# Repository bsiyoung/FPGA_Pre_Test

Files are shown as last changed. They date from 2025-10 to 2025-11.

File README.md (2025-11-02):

# FPGA_Pre_Test

This simple project is for testing power rails and external oscillator to use them on FPGA circuit design.

## 1. Objectives
1. Check power rails ON/OFF sequencing works properly
2. Check oscillator(25MHz) works properly
3. Get output voltage ripple data by
    + different output capacitance(~200uF) of buck converter
    + different output voltages(1.0~5.0V) of buck converter
    + different load(resistive, ~1.5W consume)

## 2. Directores
|Directory|Description|
|---|---|
|calculation|files for calculation|
|datasheet|datasheets of components|
|diagrams|diagrams images|
|eda_model|EDA model files for KiCAD|
|kicad_proj|KiCAD project directory|
|pcb|PCB images and gerber file|
|readme_img|image for readme file|
|schematic|schematic jpg and pdf file|

## 3. Architecture Diagram
### 3.1 Module Diagram
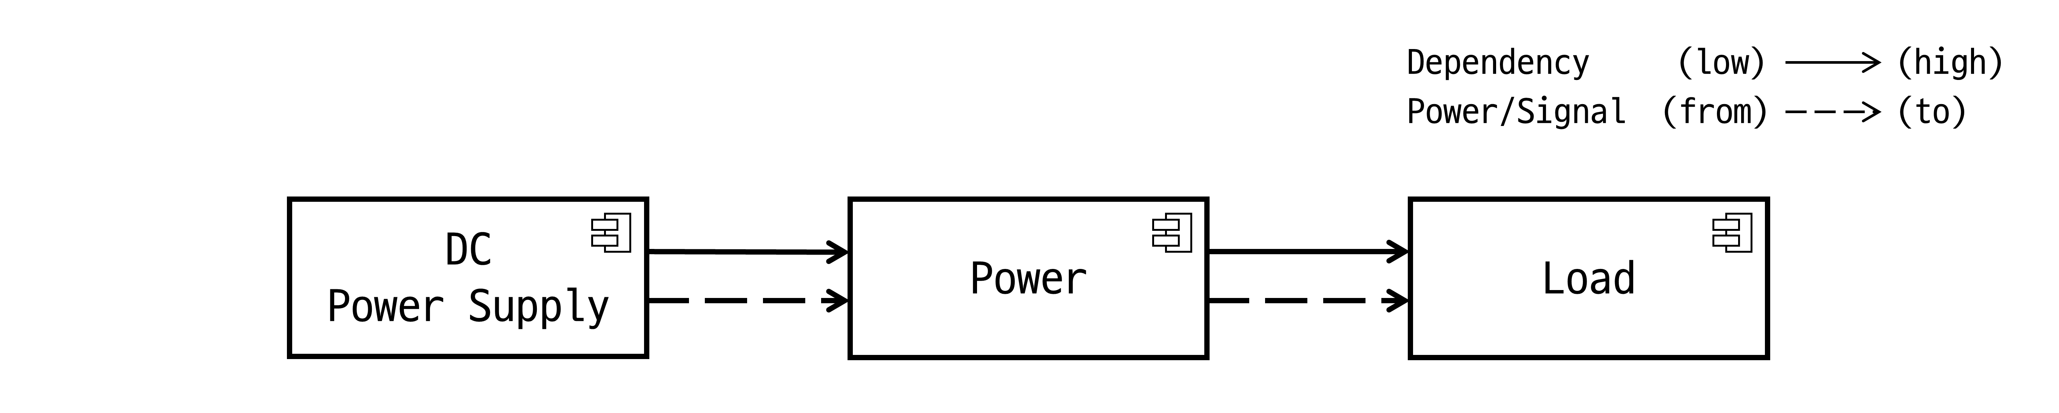
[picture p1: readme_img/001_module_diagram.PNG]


### 3.2 Block Diagram
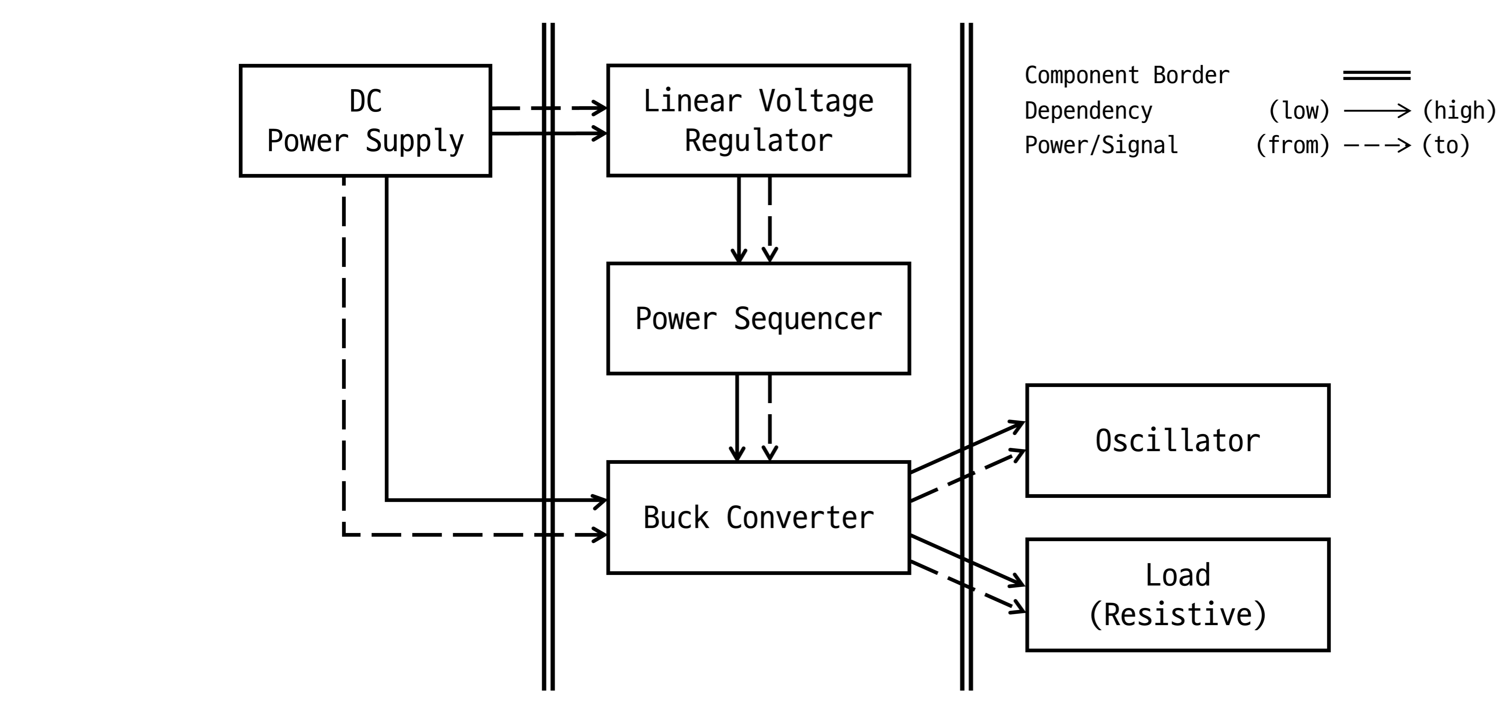
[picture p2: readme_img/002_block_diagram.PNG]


### 3.3 Ports Diagram
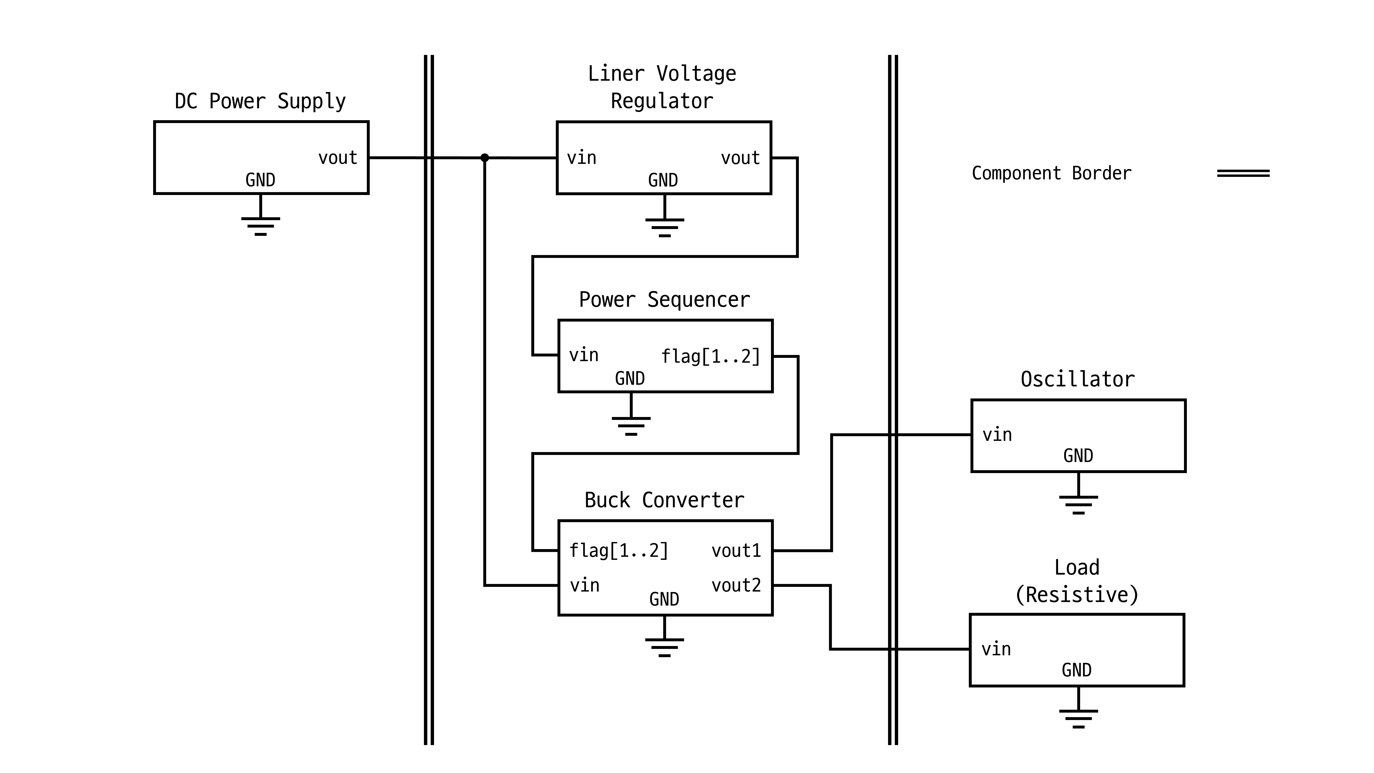
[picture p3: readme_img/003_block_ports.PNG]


## 4. Circuit Schematic
Footprints of resistors R16~20 will be used as solder jumper.

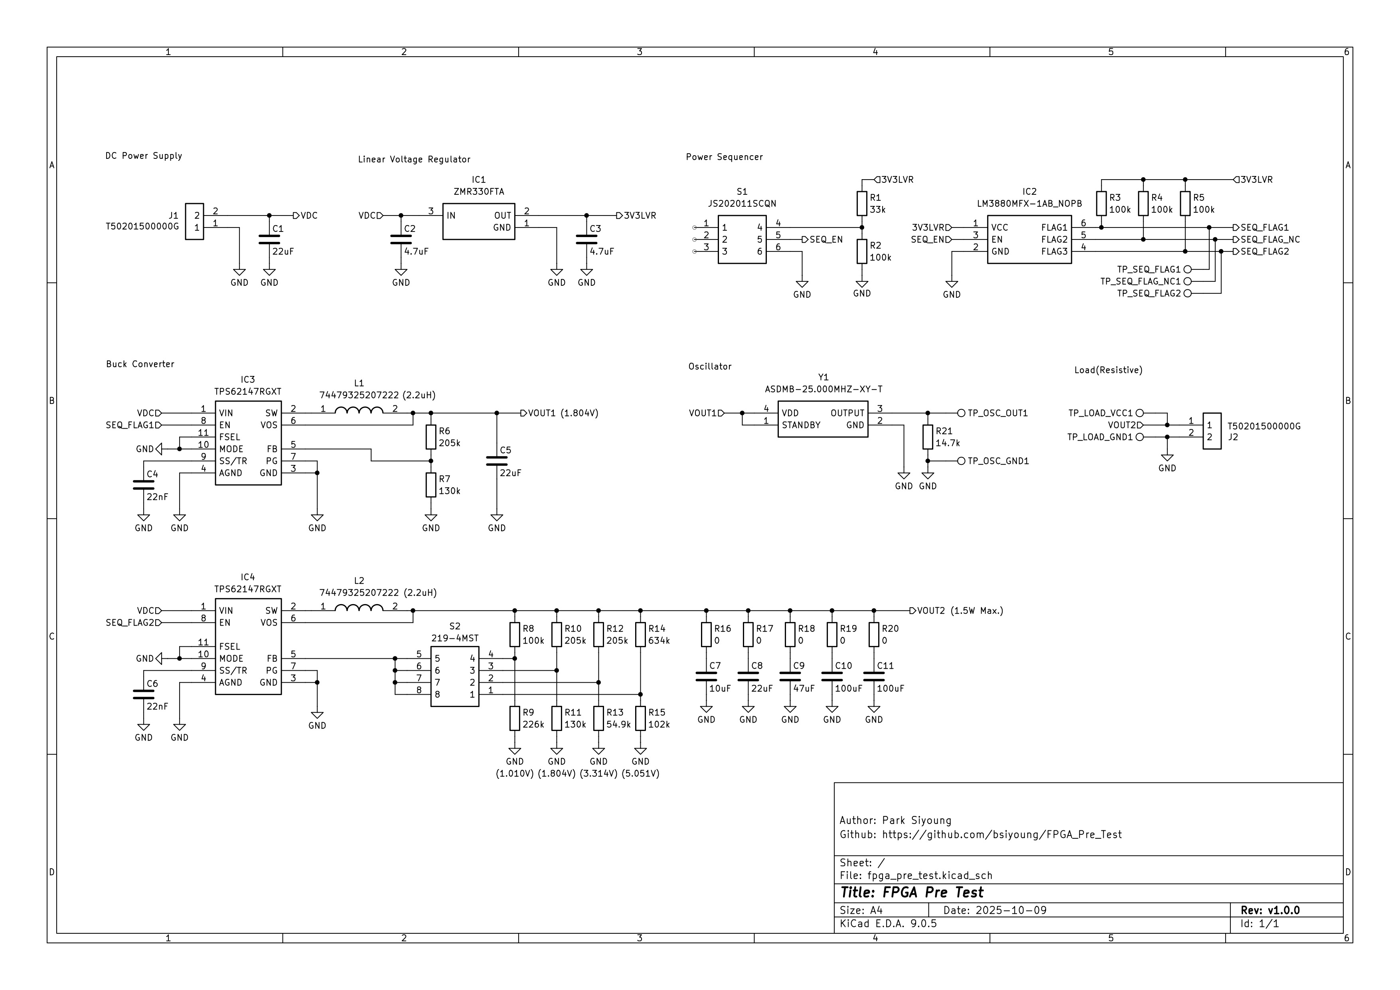
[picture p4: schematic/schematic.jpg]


</br>
Date of basis for price calculation : 2025.10.21. </br>
Refer to <a href="./component_list.xlsx">component_list.xlsx</a> for details. </br>
* Exclude PCB(USD$20.84/5pcs) and resistive load(USD$8.40).

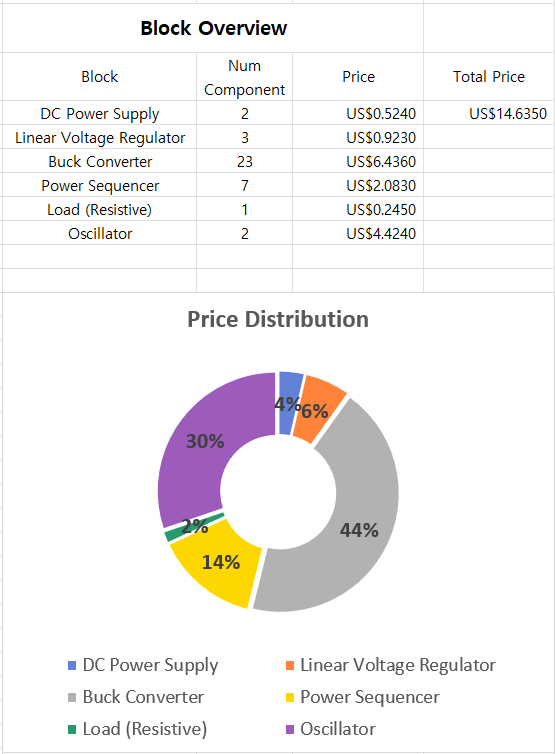
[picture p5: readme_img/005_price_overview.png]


</br>
<b>Total: USD$27.203/pcs</b> (incldue PCB and resistive load)

## 5. PCB Design
Manufacturer : JLC PCB </br>
Gerber File : ./pcb/pcb_gerber.zip (zip file of ./kicad_proj/output)

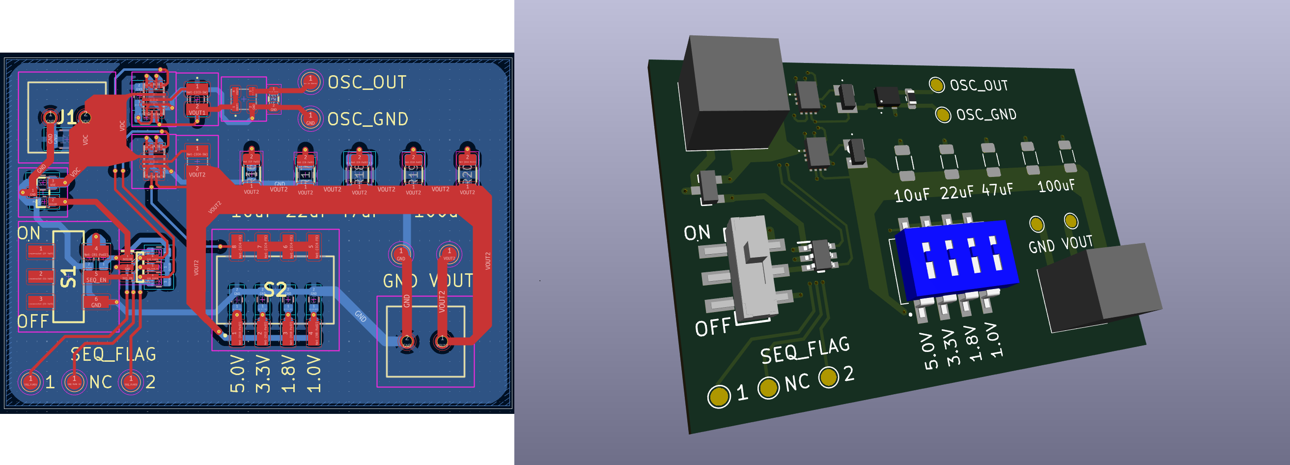
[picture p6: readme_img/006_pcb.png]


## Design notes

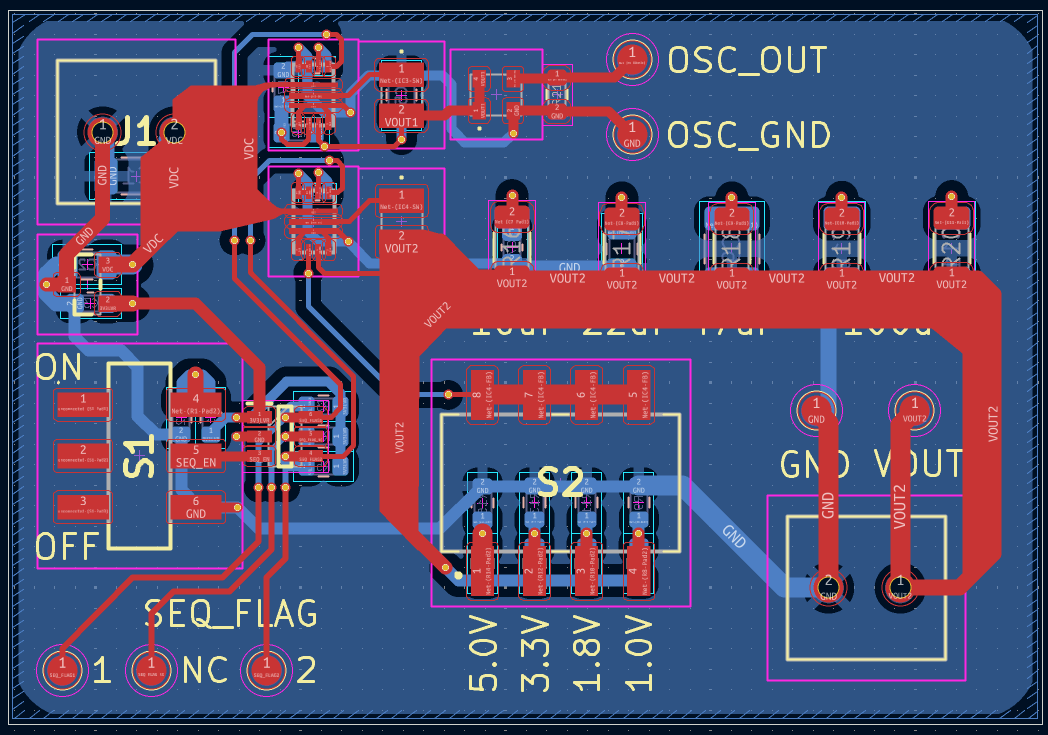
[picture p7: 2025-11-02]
pcb/pcb.png

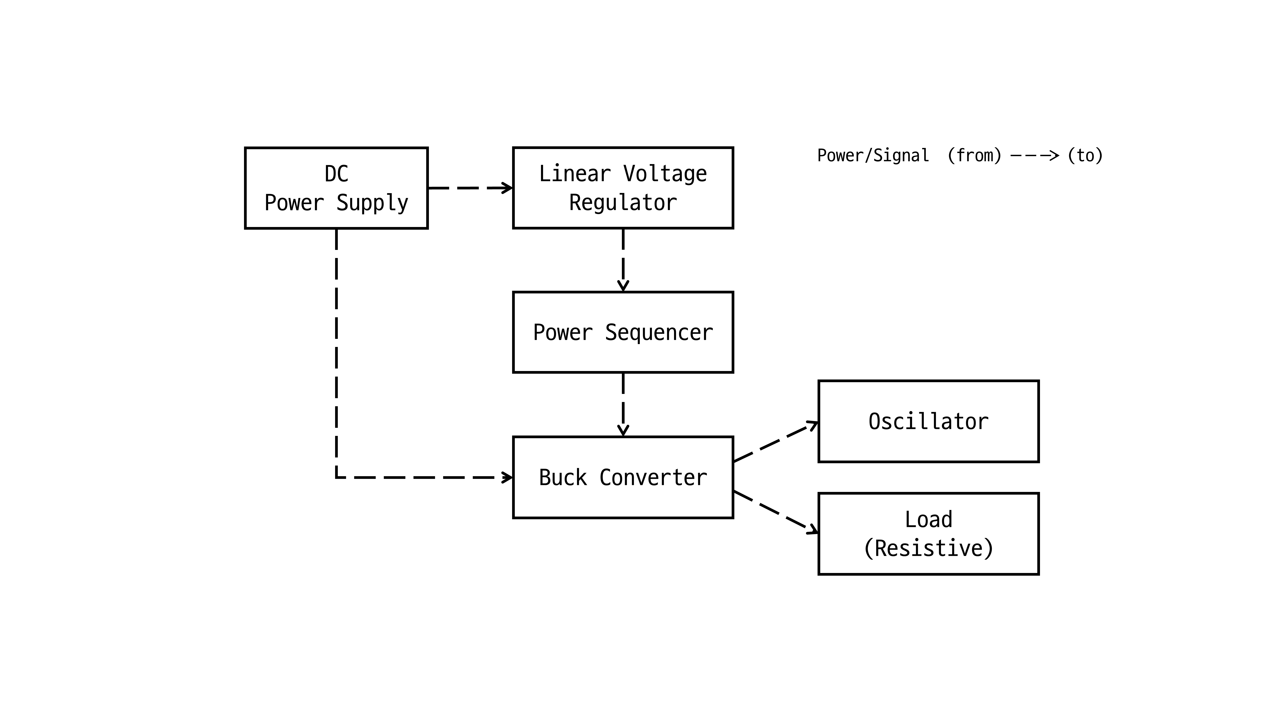
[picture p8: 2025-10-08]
diagrams/003_power_and_signal_flow.PNG

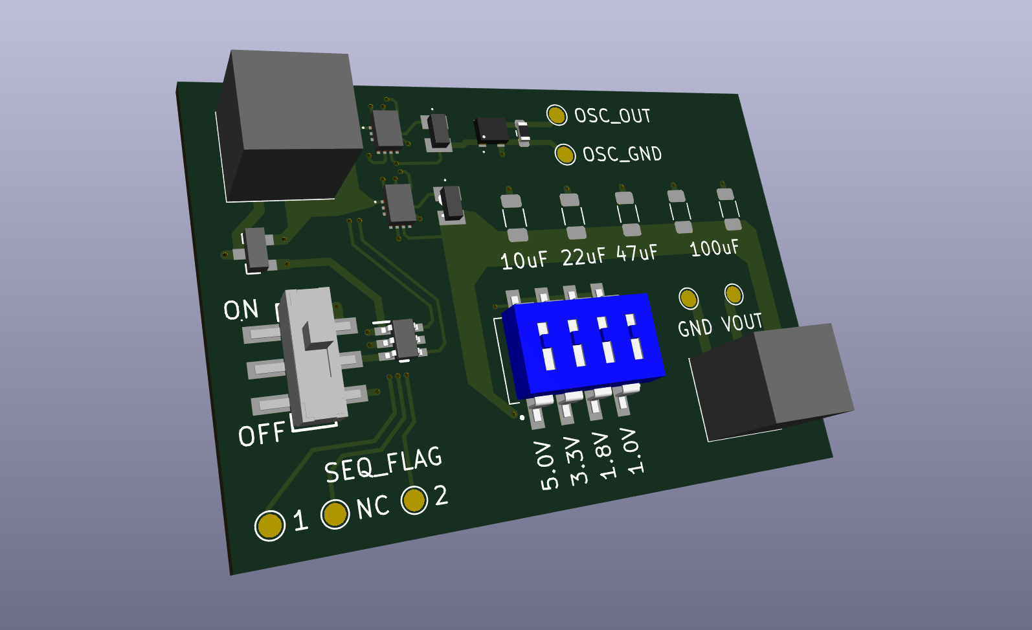
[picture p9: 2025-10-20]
pcb/pcb_3d_render.png

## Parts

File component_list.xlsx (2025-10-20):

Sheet: Overview
Date of Basis : 2025.10.21.
Components |  |  |  |  | Components (Grouped By Code) |  |  |  |  |  |  | Block Overview
No. | Block | Reference | Code | Mfr. | No. | Code | Mfr. | Unit Price | Qty | Price | Total Price | Block | Num Component | Price | Total Price
1 | DC Power Supply | C1 | EMK316BB7226ML-T | TAIYO YUDEN | 1 | EMK316BB7226ML-T | TAIYO YUDEN | US$0.2790 | 1 | US$0.2790 | US$14.6350 | DC Power Supply | 2 | US$0.5240 | US$14.6350
2 | Linear Voltage Regulator | C2 | GRM21BR71C475ME51K | Murata Electronics | 2 | GRM21BR71C475ME51K | Murata Electronics | US$0.0450 | 1 | US$0.0450 |  | Linear Voltage Regulator | 3 | US$0.9230
3 | Linear Voltage Regulator | C3 | GRM188Z71A475ME15D | Murata Electronics | 3 | GRM188Z71A475ME15D | Murata Electronics | US$0.0880 | 1 | US$0.0880 |  | Buck Converter | 23 | US$6.4360
4 | Buck Converter | C4 | GXT155R71C223KE01D | Murata Electronics | 4 | GXT155R71C223KE01D | Murata Electronics | US$0.0440 | 2 | US$0.0880 |  | Power Sequencer | 7 | US$2.0830
5 | Buck Converter | C5 | CL21A226MAYNNNE | Samsung Electro-Mechanics | 5 | CL21A226MAYNNNE | Samsung Electro-Mechanics | US$0.0430 | 2 | US$0.0860 |  | Load (Resistive) | 1 | US$0.2450
6 | Buck Converter | C6 | GXT155R71C223KE01D | Murata Electronics | 6 | CL10A106KP8NNNC | Samsung Electro-Mechanics | US$0.0230 | 1 | US$0.0230 |  | Oscillator | 2 | US$4.4240
7 | Buck Converter | C7 | CL10A106KP8NNNC | Samsung Electro-Mechanics | 7 | CL32B476MPJNNNE | Samsung Electro-Mechanics | US$0.2790 | 1 | US$0.2790
8 | Buck Converter | C8 | CL21A226MAYNNNE | Samsung Electro-Mechanics | 8 | GRM31CR61A107MEA8L | Murata Electronics | US$0.2240 | 2 | US$0.4480
9 | Buck Converter | C9 | CL32B476MPJNNNE | Samsung Electro-Mechanics | 9 | ZMR330FTA | Diodes Incorporated | US$0.7900 | 1 | US$0.7900
10 | Buck Converter | C10 | GRM31CR61A107MEA8L | Murata Electronics | 10 | LM3880MFX-1AB/NOPB | Texas Instruments | US$1.1400 | 1 | US$1.1400
11 | Buck Converter | C11 | GRM31CR61A107MEA8L | Murata Electronics | 11 | TPS62147RGXR | Texas Instruments | US$1.8100 | 2 | US$3.6200
12 | Linear Voltage Regulator | IC1 | ZMR330FTA | Diodes Incorporated | 12 | T50201500000G | Amphenol Anytek | US$0.2450 | 2 | US$0.4900
13 | Power Sequencer | IC2 | LM3880MFX-1AB/NOPB | Texas Instruments | 13 | 74479325207222 | Wurth Elektronik | US$0.3000 | 2 | US$0.6000
14 | Buck Converter | IC3 | TPS62147RGXR | Texas Instruments | 14 | RN73R1JTTD3302B25 | KOA Speer | US$0.0620 | 1 | US$0.0620
15 | Buck Converter | IC4 | TPS62147RGXR | Texas Instruments | 15 | RT0603BRD07100KL | YAGEO | US$0.0550 | 5 | US$0.2750
16 | DC Power Supply | J1 | T50201500000G | Amphenol Anytek | 16 | ERA-3AEB2053V | Panasonic | US$0.0540 | 3 | US$0.1620
17 | Load (Resistive) | J2 | T50201500000G | Amphenol Anytek | 17 | ERA-3AEB134V | Panasonic | US$0.0540 | 2 | US$0.1080
18 | Buck Converter | L1 | 74479325207222 | Wurth Elektronik | 18 | RS73F1JTTD2263B | KOA Speer | US$0.1580 | 1 | US$0.1580
19 | Buck Converter | L2 | 74479325207222 | Wurth Elektronik | 19 | ERA-3AEB5492V | Panasonic | US$0.0540 | 1 | US$0.0540
20 | Power Sequencer | R1 | RN73R1JTTD3302B25 | KOA Speer | 20 | RT0603BRD07634KL | YAGEO | US$0.0770 | 1 | US$0.0770
21 | Power Sequencer | R2 | RT0603BRD07100KL | YAGEO | 21 | ERA-3AEB1023V | Panasonic | US$0.0520 | 1 | US$0.0520
22 | Power Sequencer | R3 | RT0603BRD07100KL | YAGEO | 22 | ERA-3AEB1472V | Panasonic | US$0.0540 | 1 | US$0.0540
23 | Power Sequencer | R4 | RT0603BRD07100KL | YAGEO | 23 | JS202011SCQN | C&K | US$0.6610 | 1 | US$0.6610
24 | Power Sequencer | R5 | RT0603BRD07100KL | YAGEO | 24 | 219-4MST | CTS Electronic Components | US$0.6260 | 1 | US$0.6260
25 | Buck Converter | R6 | ERA-3AEB2053V | Panasonic | 25 | ASDMB-25.000MHZ-XY-T | ABRACON | US$4.3700 | 1 | US$4.3700
26 | Buck Converter | R7 | ERA-3AEB134V | Panasonic
27 | Buck Converter | R8 | RT0603BRD07100KL | YAGEO
28 | Buck Converter | R9 | RS73F1JTTD2263B | KOA Speer
29 | Buck Converter | R10 | ERA-3AEB2053V | Panasonic
30 | Buck Converter | R11 | ERA-3AEB134V | Panasonic
31 | Buck Converter | R12 | ERA-3AEB2053V | Panasonic
32 | Buck Converter | R13 | ERA-3AEB5492V | Panasonic
33 | Buck Converter | R14 | RT0603BRD07634KL | YAGEO
34 | Buck Converter | R15 | ERA-3AEB1023V | Panasonic
35 | Buck Converter | R16
36 | Buck Converter | R17
37 | Buck Converter | R18
38 | Buck Converter | R19
39 | Buck Converter | R20
40 | Oscillator | R21 | ERA-3AEB1472V | Panasonic
41 | Power Sequencer | S1 | JS202011SCQN | C&K
42 | Buck Converter | S2 | 219-4MST | CTS Electronic Components
43 | Oscillator | Y1 | ASDMB-25.000MHZ-XY-T | ABRACON

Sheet: DC Power Supply
DC Power Supply
No. | Reference | Code | Mfr. | No. | Code | Mfr. | Unit Price | Qty | Price | Total Price
1 | C1 | EMK316BB7226ML-T | TAIYO YUDEN | 1 | EMK316BB7226ML-T | TAIYO YUDEN | US$0.2790 | 1 | US$0.2790 | US$0.5240
2 | J1 | T50201500000G | Amphenol Anytek | 2 | T50201500000G | Amphenol Anytek | US$0.2450 | 1 | US$0.2450

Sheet: Power Sequencer
Power Sequencer
No. | Reference | Code | Mfr. | No. | Code | Mfr. | Unit Price | Qty | Price | Total Price
1 | IC2 | LM3880MFX-1AB/NOPB | Texas Instruments | 1 | LM3880MFX-1AB/NOPB | Texas Instruments | US$1.1400 | 1 | US$1.1400 | US$2.0830
2 | R1 | RN73R1JTTD3302B25 | KOA Speer | 2 | RN73R1JTTD3302B25 | KOA Speer | US$0.0620 | 1 | US$0.0620
3 | R2 | RT0603BRD07100KL | YAGEO | 3 | RT0603BRD07100KL | YAGEO | US$0.0550 | 4 | US$0.2200
4 | R3 | RT0603BRD07100KL | YAGEO | 4 | JS202011SCQN | C&K | US$0.6610 | 1 | US$0.6610
5 | R4 | RT0603BRD07100KL | YAGEO
6 | R5 | RT0603BRD07100KL | YAGEO
7 | S1 | JS202011SCQN | C&K

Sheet: Linear Voltage Regulator
Linear Voltage Regulator
No. | Reference | Code | Mfr. | No. | Code | Mfr. | Unit Price | Qty | Price | Total Price
1 | C2 | GRM21BR71C475ME51K | Murata Electronics | 1 | GRM21BR71C475ME51K | Murata Electronics | US$0.0450 | 1 | US$0.0450 | US$0.9230
2 | C3 | GRM188Z71A475ME15D | Murata Electronics | 2 | GRM188Z71A475ME15D | Murata Electronics | US$0.0880 | 1 | US$0.0880
3 | IC1 | ZMR330FTA | Diodes Incorporated | 3 | ZMR330FTA | Diodes Incorporated | US$0.7900 | 1 | US$0.7900

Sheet: Buck Converter
Buck Converter
No. | Reference | Code | Mfr. | No. | Code | Mfr. | Unit Price | Qty | Price | Total Price
1 | C4 | GXT155R71C223KE01D | Murata Electronics | 1 | GXT155R71C223KE01D | Murata Electronics | US$0.0440 | 2 | US$0.0880 | US$6.4360
2 | C5 | CL21A226MAYNNNE | Samsung Electro-Mechanics | 2 | CL21A226MAYNNNE | Samsung Electro-Mechanics | US$0.0430 | 2 | US$0.0860
3 | C6 | GXT155R71C223KE01D | Murata Electronics | 3 | CL10A106KP8NNNC | Samsung Electro-Mechanics | US$0.0230 | 1 | US$0.0230
4 | C7 | CL10A106KP8NNNC | Samsung Electro-Mechanics | 4 | CL32B476MPJNNNE | Samsung Electro-Mechanics | US$0.2790 | 1 | US$0.2790
5 | C8 | CL21A226MAYNNNE | Samsung Electro-Mechanics | 5 | GRM31CR61A107MEA8L | Murata Electronics | US$0.2240 | 2 | US$0.4480
6 | C9 | CL32B476MPJNNNE | Samsung Electro-Mechanics | 6 | TPS62147RGXR | Texas Instruments | US$1.8100 | 2 | US$3.6200
7 | C10 | GRM31CR61A107MEA8L | Murata Electronics | 7 | 74479325207222 | Wurth Elektronik | US$0.3000 | 2 | US$0.6000
8 | C11 | GRM31CR61A107MEA8L | Murata Electronics | 8 | ERA-3AEB2053V | Panasonic | US$0.0540 | 3 | US$0.1620
9 | IC3 | TPS62147RGXR | Texas Instruments | 9 | ERA-3AEB134V | Panasonic | US$0.0540 | 2 | US$0.1080
10 | IC4 | TPS62147RGXR | Texas Instruments | 10 | RT0603BRD07100KL | YAGEO | US$0.0550 | 1 | US$0.0550
11 | L1 | 74479325207222 | Wurth Elektronik | 11 | RS73F1JTTD2263B | KOA Speer | US$0.1580 | 1 | US$0.1580
12 | L2 | 74479325207222 | Wurth Elektronik | 12 | ERA-3AEB5492V | Panasonic | US$0.0540 | 1 | US$0.0540
13 | R6 | ERA-3AEB2053V | Panasonic | 13 | RT0603BRD07634KL | YAGEO | US$0.0770 | 1 | US$0.0770
14 | R7 | ERA-3AEB134V | Panasonic | 14 | ERA-3AEB1023V | Panasonic | US$0.0520 | 1 | US$0.0520
15 | R8 | RT0603BRD07100KL | YAGEO | 15 | 219-4MST | CTS Electronic Components | US$0.6260 | 1 | US$0.6260
16 | R9 | RS73F1JTTD2263B | KOA Speer
17 | R10 | ERA-3AEB2053V | Panasonic
18 | R11 | ERA-3AEB134V | Panasonic
19 | R12 | ERA-3AEB2053V | Panasonic
20 | R13 | ERA-3AEB5492V | Panasonic
21 | R14 | RT0603BRD07634KL | YAGEO
22 | R15 | ERA-3AEB1023V | Panasonic
23 | S2 | 219-4MST | CTS Electronic Components

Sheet: Oscillator
Oscillator
No. | Reference | Code | Mfr. | No. | Code | Mfr. | Unit Price | Qty | Price | Total Price
1 | R21 | ERA-3AEB1472V | Panasonic | 1 | ERA-3AEB1472V | Panasonic | US$0.0540 | 1 | US$0.0540 | US$4.4240
2 | Y1 | ASDMB-25.000MHZ-XY-T | ABRACON | 2 | ASDMB-25.000MHZ-XY-T | ABRACON | US$4.3700 | 1 | US$4.3700

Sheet: Load (Resistive)
Load (Resistive)
No. | Reference | Code | Mfr. | No. | Code | Mfr. | Unit Price | Qty | Price | Total Price
1 | J2 | T50201500000G | Amphenol Anytek | 1 | T50201500000G | Amphenol Anytek | US$0.2450 | 1 | US$0.2450 | US$0.2450

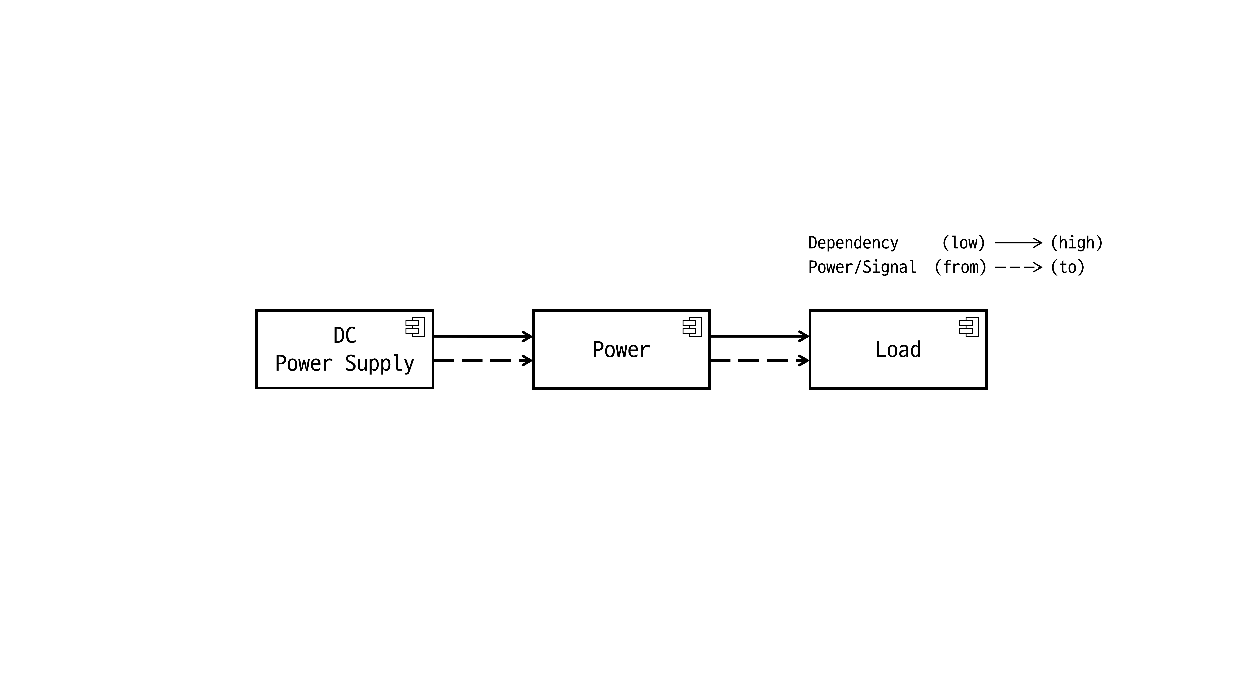
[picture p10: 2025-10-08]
diagrams/001_components.PNG

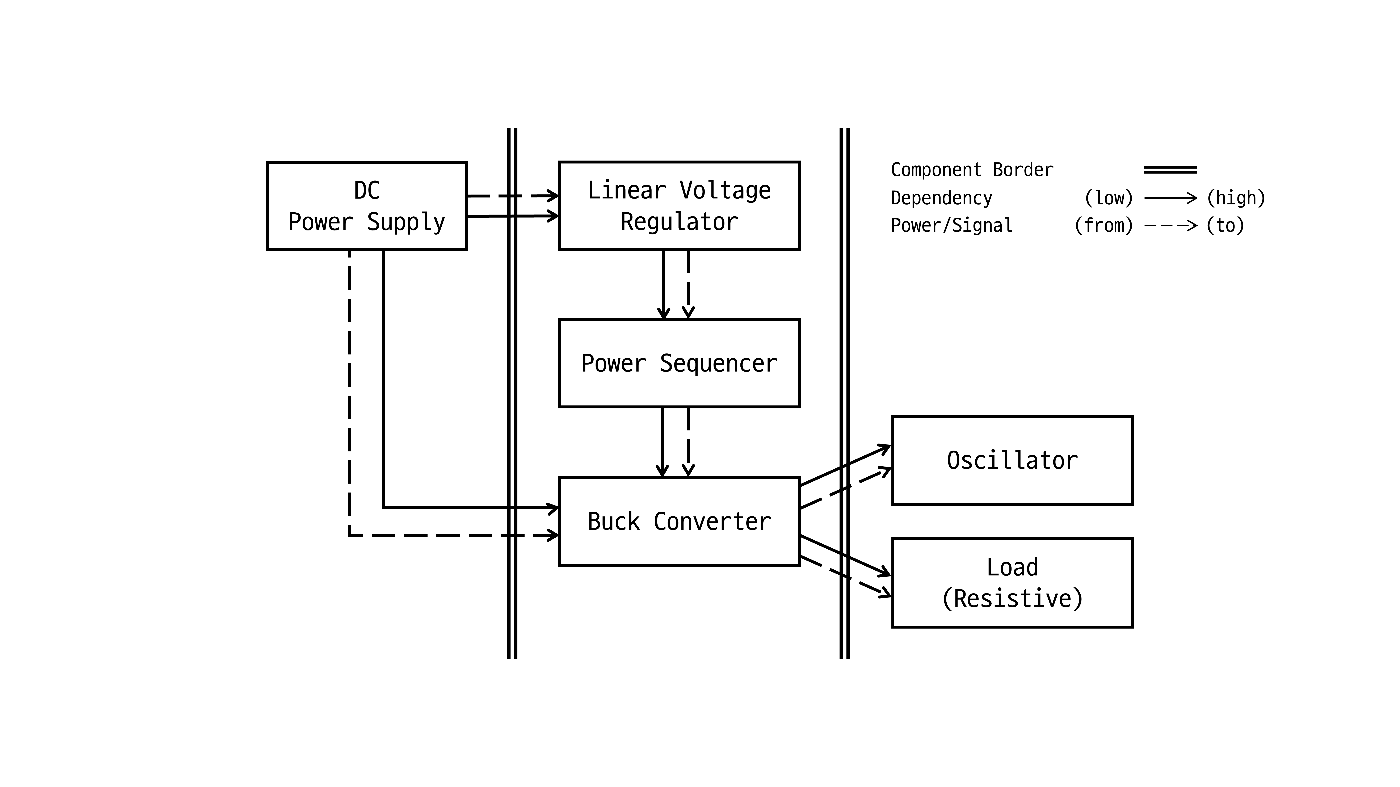
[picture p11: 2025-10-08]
diagrams/002_component_borders.PNG

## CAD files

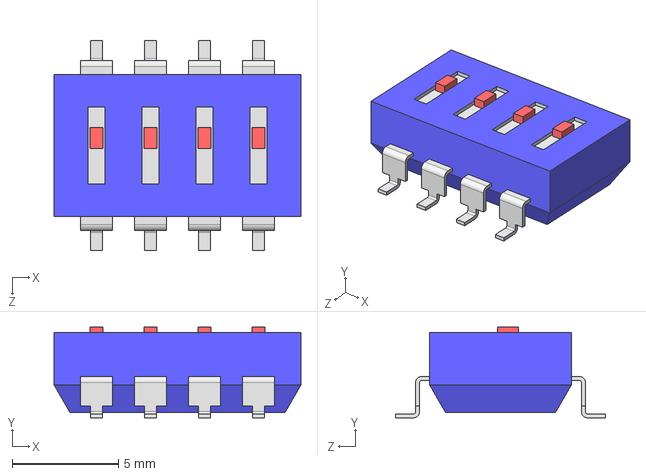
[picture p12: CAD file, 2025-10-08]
eda_model/219-4MST/3D/219-4MST.stp
11.6 x 4.27 x 9.91 mm

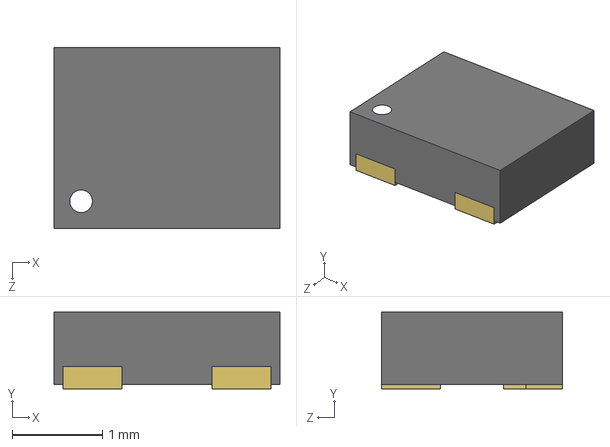
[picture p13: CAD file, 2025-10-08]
eda_model/ASDMB-25.000MHZ-XY-T/3D/ASDMB-25.000MHZ-XY-T.stp
2.50 x 0.85 x 2.00 mm

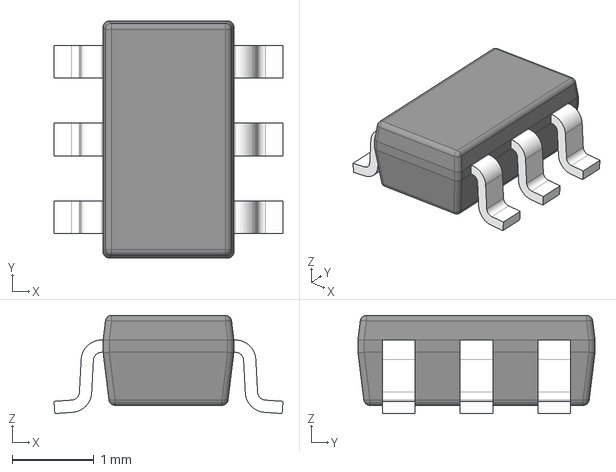
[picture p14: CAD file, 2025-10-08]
eda_model/LM3880MFX-1AB_NOPB/3D/LM3880MFX-1AB_NOPB.stp
2.80 x 2.90 x 1.20 mm
BODY-SOT
LEAD-SOT x 6

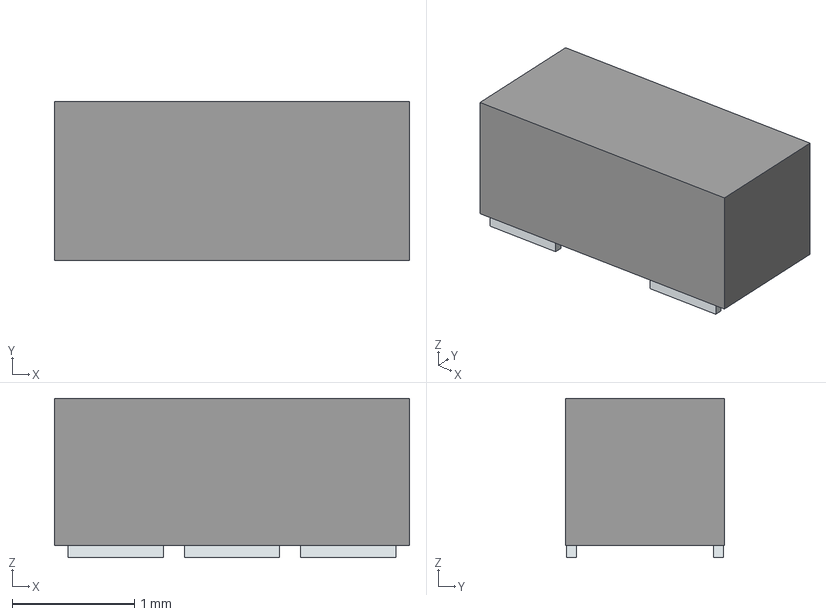
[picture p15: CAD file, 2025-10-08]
eda_model/ZMR330FTA/3D/ZMR330FTA.stp
2.90 x 1.30 x 1.30 mm
Pins

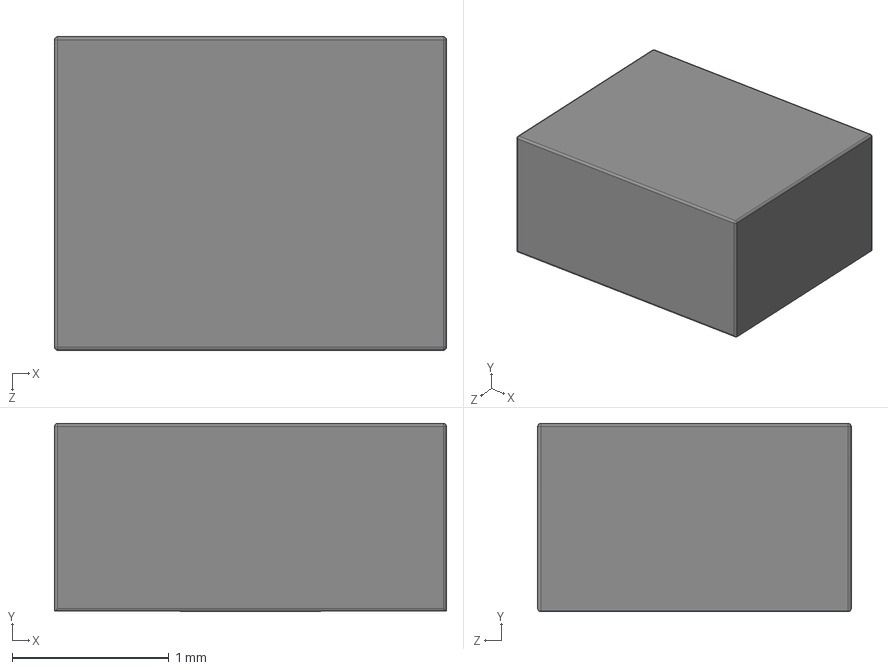
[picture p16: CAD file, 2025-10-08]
eda_model/74479325207222/3D/74479325207222.stp
2.50 x 1.20 x 2.00 mm

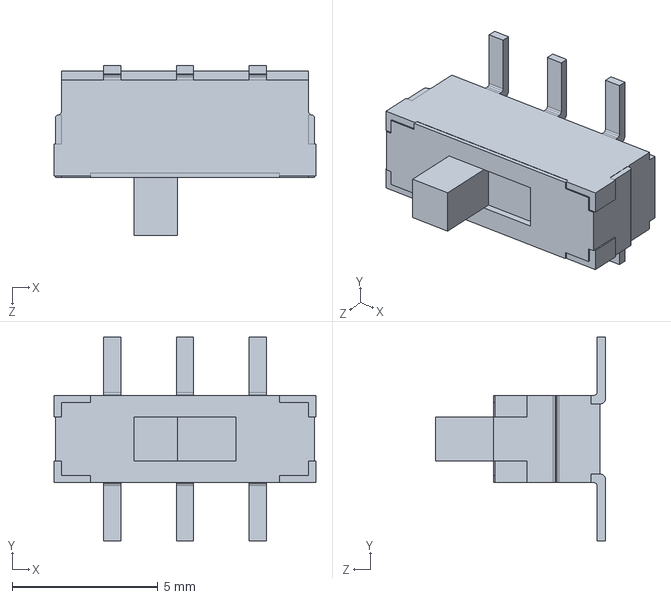
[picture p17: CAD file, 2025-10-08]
eda_model/JS202011SCQN/3D/JS202011SCQN.stp
9.00 x 7.00 x 5.85 mm

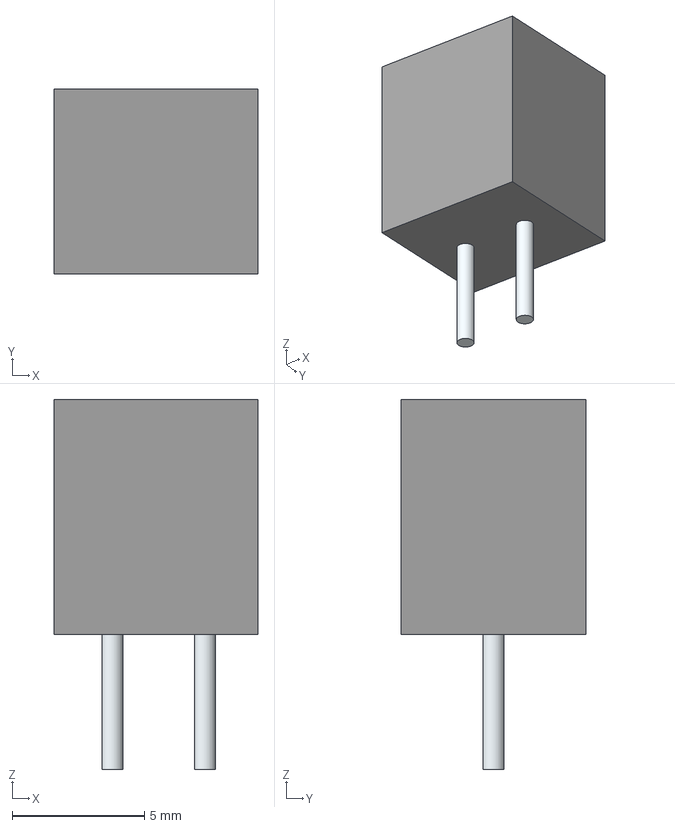
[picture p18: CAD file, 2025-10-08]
eda_model/T50201500000G/3D/T50201500000G.stp
7.70 x 7.00 x 14.0 mm
Leads x 2

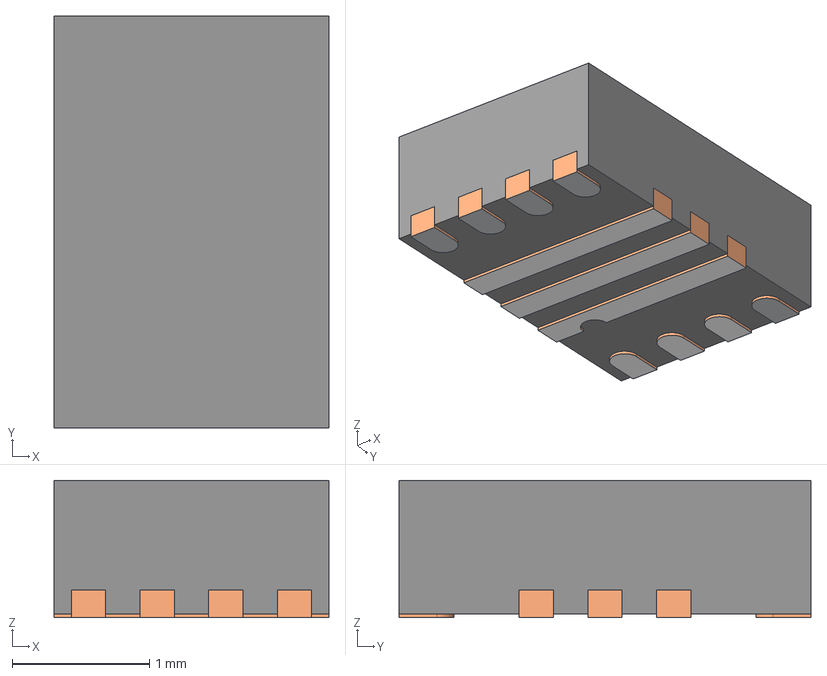
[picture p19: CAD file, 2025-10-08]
eda_model/TPS62147RGXT/3D/TPS62147RGXT.stp
2.00 x 3.00 x 1.00 mm
FRAME-RGX0011A
BODY-QFN
PIN1-ID

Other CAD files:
eda_model/219-4MST/Allegro/2194mst.psm
eda_model/219-4MST/DEHDL/219_4mst/chips/chips.prt
eda_model/74479325207222/Allegro/74479325207222.psm
eda_model/74479325207222/DEHDL/74479325207222/chips/chips.prt
eda_model/ASDMB-25.000MHZ-XY-T/Allegro/abraconasdmb.psm
eda_model/ASDMB-25.000MHZ-XY-T/DEHDL/asdmb_25.000mhz_xy_t/chips/chips.prt
eda_model/JS202011SCQN/Allegro/js202011scqn.psm
eda_model/JS202011SCQN/DEHDL/js202011scqn/chips/chips.prt
eda_model/LM3880MFX-1AB_NOPB/Allegro/sot95p280x145-6n.psm
eda_model/LM3880MFX-1AB_NOPB/DEHDL/lm3880mfx_1ab_nopb/chips/chips.prt
eda_model/T50201500000G/3D/T50201500000G.stl
eda_model/T50201500000G/Allegro/t50201500000g.psm
eda_model/T50201500000G/DEHDL/t50201500000g/chips/chips.prt
eda_model/TPS62147RGXT/Allegro/tps62147rgxt.psm
eda_model/TPS62147RGXT/DEHDL/tps62147rgxt/chips/chips.prt
eda_model/ZMR330FTA/Allegro/zmr330fta.psm
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

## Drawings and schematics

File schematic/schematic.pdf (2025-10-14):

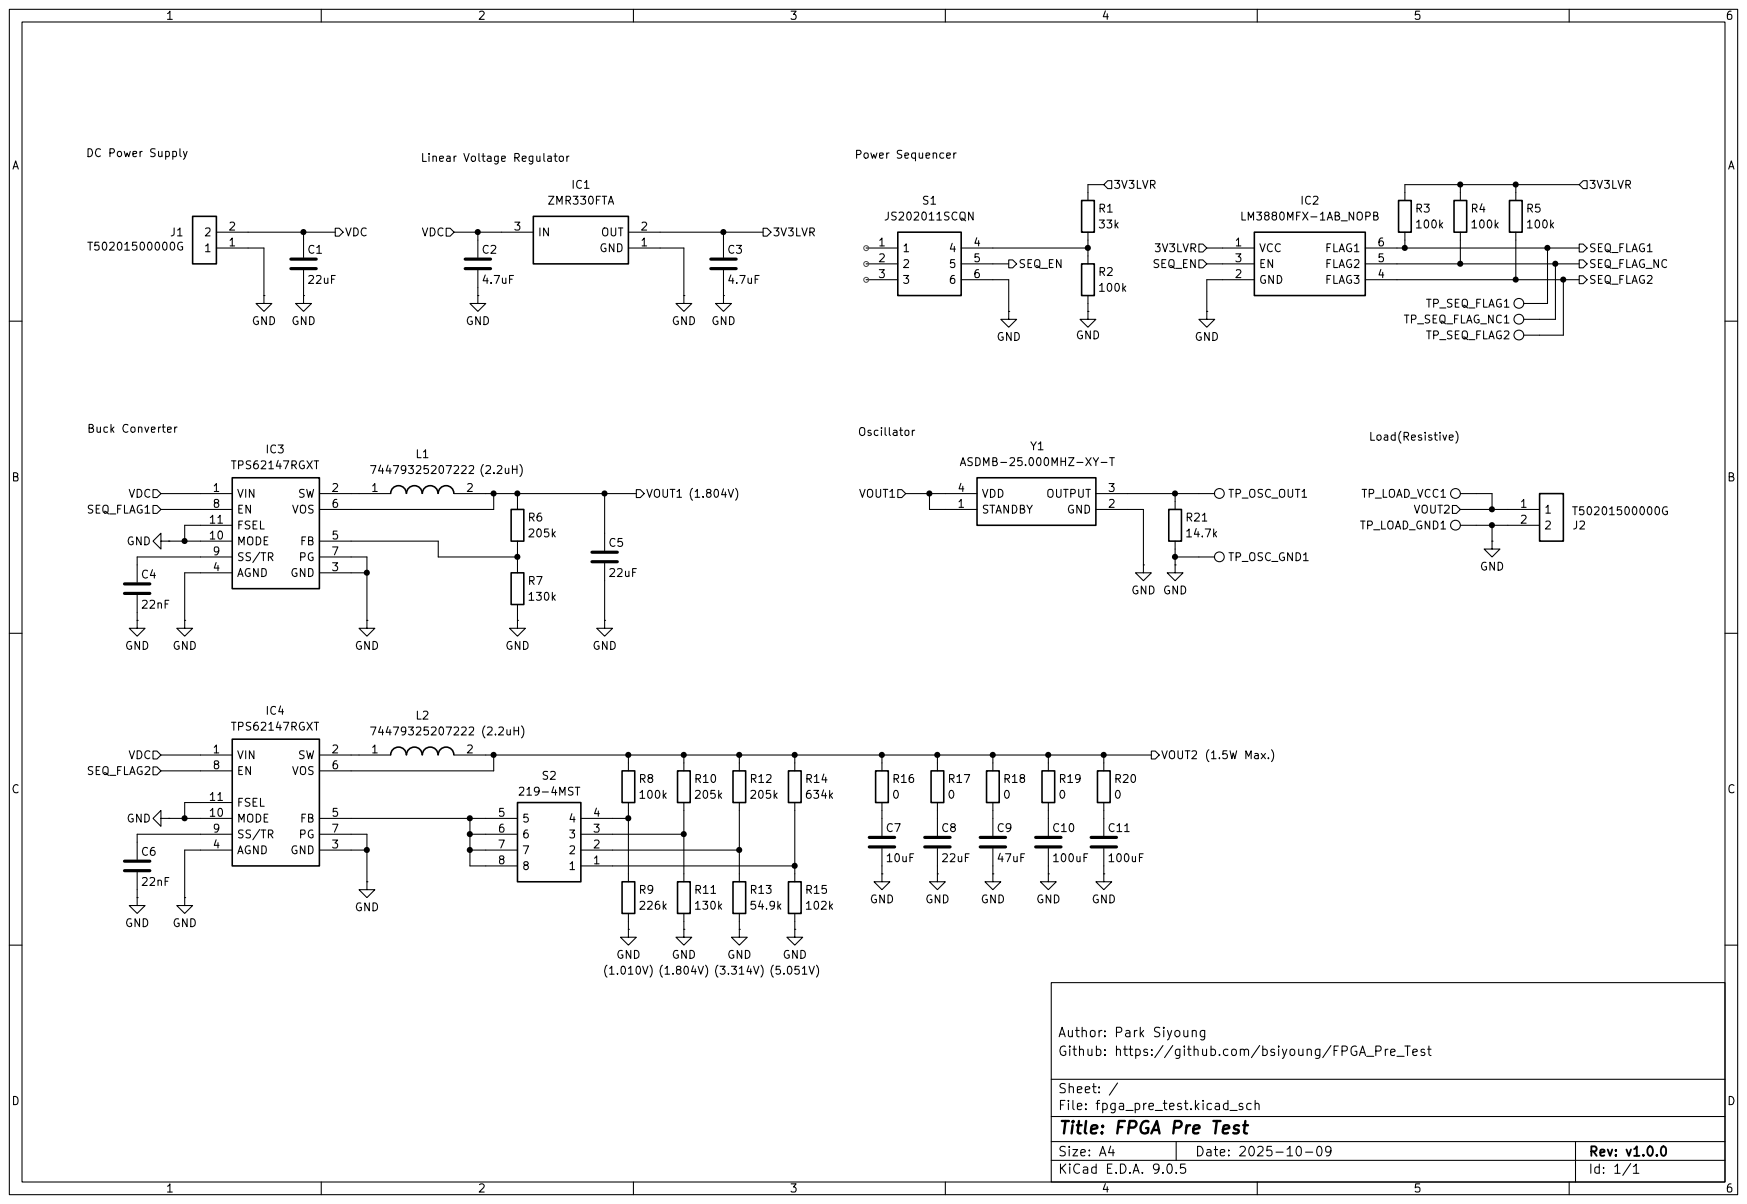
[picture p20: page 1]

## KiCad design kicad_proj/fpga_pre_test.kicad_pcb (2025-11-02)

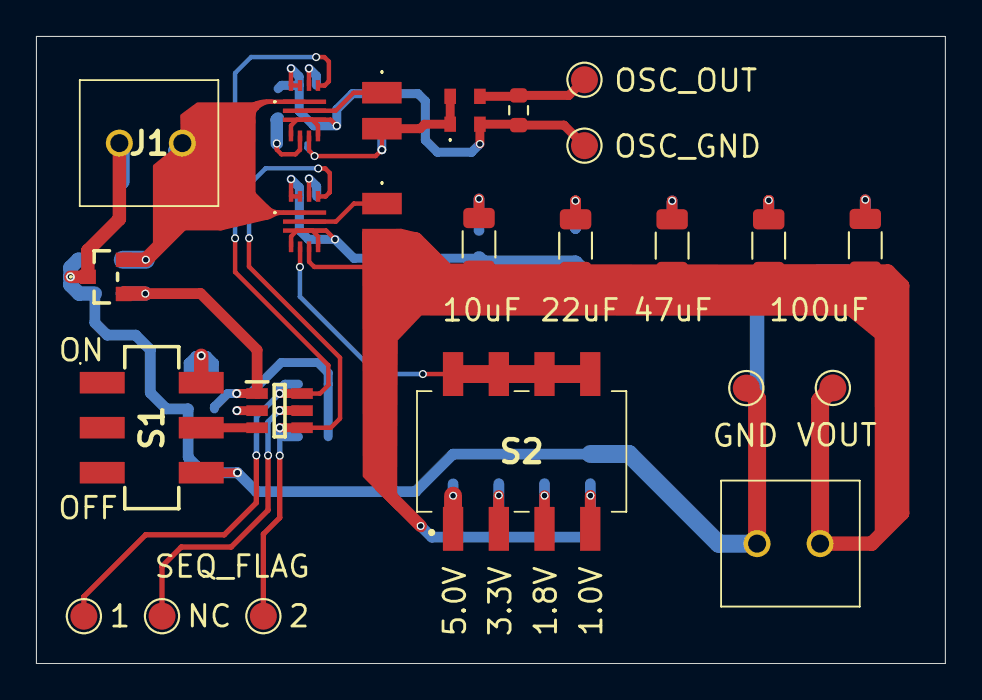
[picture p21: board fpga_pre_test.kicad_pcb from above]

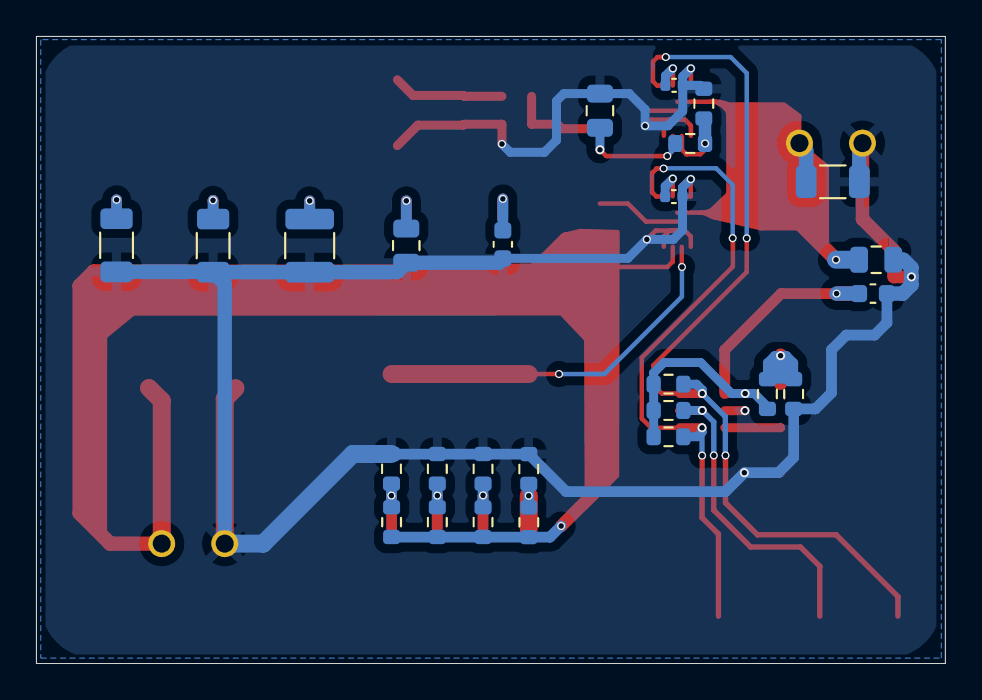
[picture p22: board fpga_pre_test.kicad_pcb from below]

Board: 2 copper layers, 50.5 x 34.8 mm, 50 parts (26 on the bottom side), 26 nets.

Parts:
C1: 22uF; C_1206_3216Metric
C2: 4.7uF; C_0805_2012Metric
C3: 4.7uF; C_0603_1608Metric
C4, C6: 22nF; C_0402_1005Metric
C5, C8: 22uF; C_0805_2012Metric
C7: 10uF; C_0603_1608Metric
C9: 47uF; C_1210_3225Metric
C10, C11: 100uF; C_1206_3216Metric
IC1: ZMR330FTA
IC2: LM3880MFX-1AB_NOPB; SOT95P280X145-6N
IC3, IC4: TPS62147RGXT
J1, J2: T50201500000G
L1, L2: 74479325207222
R1: 33k; R_0603_1608Metric
R2, R3, R4, R5, R8: 100k; R_0603_1608Metric
R6, R10, R12: 205k; R_0603_1608Metric
R7, R11: 130k; R_0603_1608Metric
R9: 226k; R_0603_1608Metric
R13: 54.9k; R_0603_1608Metric
R14: 634k; R_0603_1608Metric
R15: 102k; R_0603_1608Metric
R16, R17, R18, R19, R20: 0; R_1206_3216Metric
R21: 14.7k; R_0603_1608Metric
S1: JS202011SCQN
S2: 219-4MST; 2194MST
TP_LOAD_GND1: TestPoint; TestPoint_Pad_D1.5mm
TP_LOAD_VCC1: TestPoint; TestPoint_Pad_D1.5mm
TP_OSC_GND1: TestPoint; TestPoint_Pad_D1.5mm
TP_OSC_OUT1: TestPoint; TestPoint_Pad_D1.5mm
TP_SEQ_FLAG1, TP_SEQ_FLAG2: TestPoint; TestPoint_Pad_D1.5mm
TP_SEQ_FLAG_NC1: TestPoint; TestPoint_Pad_D1.5mm
Y1: ASDMB-25.000MHZ-XY-T; AbraconASDMB

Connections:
/3V3LVR: C3.1, IC1.2 (OUT), IC2.1 (VCC), R1.1, R3.1, R4.1, R5.1
/SEQ_EN: IC2.3 (EN), S1.5
/SEQ_FLAG1: IC2.6 (FLAG1), IC3.8 (EN), R3.2, TP_SEQ_FLAG1.1
/SEQ_FLAG2: IC2.4 (FLAG3), IC4.8 (EN), R5.2, TP_SEQ_FLAG2.1
/SEQ_FLAG_NC: IC2.5 (FLAG2), R4.2, TP_SEQ_FLAG_NC1.1
/VDC: C1.1, C2.1, IC1.3 (IN), IC3.1 (VIN), IC4.1 (VIN), J1.2
/VOUT1: C5.1, IC3.6 (VOS), L1.2, R6.1, Y1.1 (STANDBY), Y1.4 (VDD)
/VOUT2: IC4.6 (VOS), J2.1, L2.2, R8.1, R10.1, R12.1, R14.1, R16.1, R17.1, R18.1, R19.1, R20.1, TP_LOAD_VCC1.1
GND: C1.2, C2.2, C3.2, C4.2, C5.2, C6.2, C7.2, C8.2, C9.2, C10.2, C11.2, IC1.1 (GND), IC2.2 (GND), IC3.3 (GND), IC3.4 (AGND), IC3.7 (PG), IC3.10 (MODE), IC3.11 (FSEL), IC4.3 (GND), IC4.4 (AGND), IC4.7 (PG), IC4.10 (MODE), IC4.11 (FSEL), J1.1, J2.2, R2.2, R7.2, R9.2, R11.2, R13.2, R15.2, R21.2, S1.6, TP_LOAD_GND1.1, TP_OSC_GND1.1, Y1.2 (GND)
unnamed: C7.1, R16.2
unnamed: C8.1, R17.2
unnamed: C9.1, R18.2
unnamed: C10.1, R19.2
unnamed: C11.1, R20.2
unnamed: IC3.5 (FB), R6.2, R7.1
unnamed: C4.1, IC3.9 (SS/TR)
unnamed: IC3.2 (SW), L1.1
unnamed: IC4.5 (FB), S2.5, S2.6, S2.7, S2.8
unnamed: C6.1, IC4.9 (SS/TR)
unnamed: IC4.2 (SW), L2.1
unnamed: R1.2, R2.1, S1.4
unnamed: R8.2, R9.1, S2.4
unnamed: R10.2, R11.1, S2.3
unnamed: R12.2, R13.1, S2.2
unnamed: R14.2, R15.1, S2.1
unnamed: R21.1, TP_OSC_OUT1.1, Y1.3 (OUTPUT)

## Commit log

2025-10-08 Add Kicad Project, Circuit Schematic Completed
    [219-4MST.SchLib, 219-4MST.stp, 2194MST.PcbLib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]
2025-10-14 Small fixes on circuit schematic
    [TPS62147_calculation.xlsx, fpga_pre_test.kicad_sch]
2025-10-14 PCB Design
    [fpga_pre_test-B_Cu.gbr, fpga_pre_test-B_Mask.gbr, fpga_pre_test-B_Paste.gbr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]
2025-10-20 PCB Gerber File Added, Component List xlsx Added
    [component_list.xlsx]
2025-11-02 Update PCB design and cost information
    [fpga_pre_test.kicad_pcb]
